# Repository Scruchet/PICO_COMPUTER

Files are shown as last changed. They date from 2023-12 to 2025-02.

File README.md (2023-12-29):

# PICO Computer Project: Motherboard

Welcome to my PICO Computer project repository. This section consolidates all the source files written in the C language used by my motherboard, as well as the electronic components created with KiCad. The primary goal of this project is to create a motherboard that can be connected to other boards (screen, keyboard, network) to build a Pico Computer.

## Part 1: Motherboard
You can find all the plans for my board in the **Motherboard_pico** directory.

### Features
This board is composed of multiple components. The main IC is the Atmega328p, which acts as the processor. The FTDI serves as the connection between the USB port and the Atmega328p (it does not include USB). The AT45DB641E is the storage component of the computer. As this component works with 3.3V signals, a buffer is needed to convert the 5V signals from the Atmega328p to 3.3V. To connect all the other cards, there are 5 HE10 connectors. All the different cards communicate using SPI (MOSI, MISO, SS, SCK).

## Part 2: Source Section (src)

This section includes all the source files written in the C language used by my motherboard. In addition to the source files, there is also a test folder to demonstrate various evaluations performed during the project's development.

### Module Details

#### Makefile
The Makefile enables project compilation and management. Refer to this file for details on compilation, linking, and other build tasks. In each directory, you can run the code (excluding files without main.c) and upload the code using the `make upload` command.

#### Memory
The Memory directory contains files related to memory management, including handling a specific flash memory (AT45DB641E).

#### Scheduler
The Scheduler module includes files necessary for implementing a scheduler. Refer to `makefile`, `scheduler.c`, and `scheduler.h` for more details.

#### SPI
The SPI module contains the files `spi.c` and `spi.h` for managing communication via the Serial Peripheral Interface (SPI) bus.

#### UART
The UART module includes the files `UART.c` and `UART.h`, dedicated to asynchronous serial communication (UART).

#### Tests
The Tests directory includes several subdirectories, each containing specific tests.

- `7seg`: Tests related to the 7-segment display (https://www.sparkfun.com/products/11441).
- `Mat_leds`: Tests for the LED matrix (https://www.sparkfun.com/products/retired/760).
- `Mem`: Tests for memory management.
- `UART_SPI`: Tests for UART and SPI modules.

# Contact
Thank you for visiting my project. If you have any comments or questions, please feel free to contact me via email at the following address: cruchetsimon@gmail.com

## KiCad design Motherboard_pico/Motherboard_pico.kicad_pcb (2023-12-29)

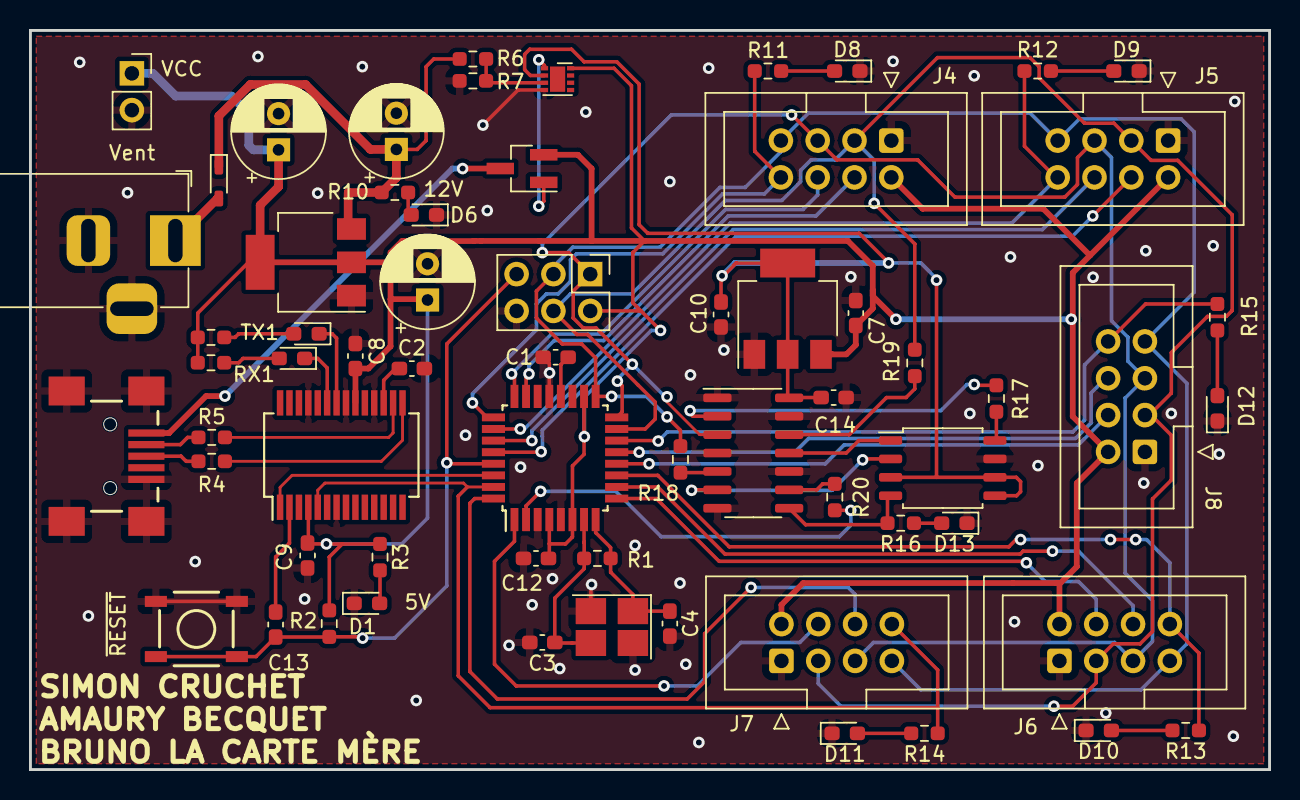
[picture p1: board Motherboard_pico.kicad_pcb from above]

Board: 2 copper layers, 85.5 x 51.0 mm, 64 parts (0 on the bottom side), 58 nets.

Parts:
C1, C8, C9, C12, C13, C14: 100nF; C_0603_1608Metric_Pad1.08x0.95mm_HandSolder
C2: C; C_0603_1608Metric_Pad1.08x0.95mm_HandSolder
C3, C4: 22pF; C_0603_1608Metric_Pad1.08x0.95mm_HandSolder
C5: 4.7µF; CP_Radial_D6.3mm_P2.50mm
C6, C11: 47µF; CP_Radial_D6.3mm_P2.50mm
C7, C10: 1µF; C_0603_1608Metric_Pad1.08x0.95mm_HandSolder
D1, D6, D8, D9, D10, D11, D12, D13: LED; LED_0603_1608Metric_Pad1.05x0.95mm_HandSolder
D7: D; D_SC-80_HandSoldering
IC1: AT45DB641E-SHN2B-T; SOIC-8_5.275x5.275mm_P1.27mm
J1: Barrel_Jack_Switch_Pin3Ring; BarrelJack_Horizontal
J2: AVR-ISP-6; PinHeader_2x03_P2.54mm_Vertical
J3: Conn_01x02_Socket; PinSocket_1x02_P2.54mm_Vertical
J4, J5, J6, J7, J8: Conn_02x04_Counter_Clockwise; IDC-Header_2x04_P2.54mm_Vertical
J9: USB_MINI-B_SMT; USB-MINIB
Q1: FDN340P; SOT-23_Handsoldering
R1: 1MΩ; R_0603_1608Metric_Pad0.98x0.95mm_HandSolder
R2: 10KΩ; R_0603_1608Metric_Pad0.98x0.95mm_HandSolder
R3, R8, R9: 500Ω; R_0603_1608Metric_Pad0.98x0.95mm_HandSolder
R4, R5: 22Ω; R_0603_1608Metric_Pad0.98x0.95mm_HandSolder
R6, R7: 10k; R_0603_1608Metric_Pad0.98x0.95mm_HandSolder
R10: 1kΩ; R_0603_1608Metric_Pad0.98x0.95mm_HandSolder
R11, R12, R13, R14, R15, R16: 1k; R_0603_1608Metric_Pad0.98x0.95mm_HandSolder
R17, R18, R19, R20: 3.3k; R_0603_1608Metric_Pad0.98x0.95mm_HandSolder
RX1: LED; LED_0603_1608Metric_Pad1.05x0.95mm_HandSolder
S1: MOMENTARY-SWITCH-SPST-2-SMD-5.2MM; TACTILE_SWITCH_SMD_5.2MM
TX1: LED; LED_0603_1608Metric_Pad1.05x0.95mm_HandSolder
U1: ATmega328P-A; TQFP-32_7x7mm_P0.8mm
U2: LM358; DFN-8-1EP_2x2mm_P0.5mm_EP1.05x1.75mm
U3: AMS1117-5.0; SOT-223-3_TabPin2
U4: AMS1117; SOT-223-3_TabPin2
U5: 74LVC125; SOIC-14_3.9x8.7mm_P1.27mm
U6: FT232RL; SSOP-28_5.3x10.2mm_P0.65mm
Y1: 16MHz; Crystal_SMD_SeikoEpson_FA238-4Pin_3.2x2.5mm_HandSoldering

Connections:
3.3V: C10.1, C14.1, IC1.3 (~RESET), IC1.5 (~WP), IC1.6 (VCC), U2.2 (-), U4.2 (VO), U5.14 (VCC)
12V: C11.1, D7.1 (K), R6.2, R10.1, U3.3 (VI)
CBUS0: RX1.1 (K), U6.23 (CBUS0)
CBUS1: TX1.1 (K), U6.22 (CBUS1)
CS1: R20.1, U1.2 (PD4)
CS1_1: IC1.4 (~CS), R16.2, U5.8
CS2: J4.8, R11.2, U1.25 (PC2)
CS3: J5.8, R12.2, U1.26 (PC3)
CS4: J6.8, R13.2, U1.11 (PD7)
CS5: J7.8, R14.2, U1.31 (PD1), U6.5 (RXD)
CS6: J8.8, R15.2, U1.14 (PB2)
D+: R4.2, U6.15 (USBD+)
D-: R5.2, U6.16 (USBD-)
GND: C1.2, C2.2, C3.2, C4.2, C5.2, C6.2, C7.2, C8.2, C9.2, C10.2, C11.2, C12.2, C14.2, D1.1 (K), D6.1 (K), D8.1 (K), D9.1 (K), D10.1 (K), D11.1 (K), D12.1 (K), D13.1 (K), IC1.7 (GND), J1.2, J1.3, J2.6 (GND), J3.2, J4.1, J5.1, J6.1, J7.1, J8.1, J9.GND, J9.S1 (SHIELD), J9.S2 (SHIELD), J9.S3 (SHIELD), J9.S4 (SHIELD), R7.2, S1.1, S1.2, U1.3 (GND), U1.5 (GND), U1.21 (GND), U2.4 (V-), U3.1 (GND), U4.1 (ADJ), U5.1, U5.4, U5.7 (GND), U5.10, U5.13, U6.7 (GND), U6.18 (GND), U6.21 (GND), U6.25 (AGND), Y1.2, Y1.4
INT1: J4.4, U1.23 (PC0)
INT2: J5.4, U1.28 (PC5)
INT3: J6.4, U1.9 (PD5)
INT4: J7.4, U1.1 (PD3)
INT5: J8.4, U1.12 (PB0)
MISO: J2.1 (MISO), J4.5, J5.5, J6.5, J7.5, J8.5, U1.16 (PB4), U5.3
MISO_1: IC1.8 (SO), R17.1
MOSI: J2.4 (MOSI), J4.3, J5.3, J6.3, J7.3, J8.3, R19.1, U1.15 (PB3)
MOSI_1: IC1.1 (SI), U5.11
unnamed: D1.2 (A), R3.2
unnamed: D6.2 (A), R10.2
unnamed: D7.2 (A), J1.1
unnamed: D8.2 (A), R11.1
unnamed: D9.2 (A), R12.1
unnamed: D10.2 (A), R13.1
unnamed: D11.2 (A), R14.1
unnamed: D12.2 (A), R15.1
unnamed: D13.2 (A), R16.1
unnamed: J9.D+, R4.1
unnamed: J9.D-, R5.1
unnamed: Q1.1 (G), U2.1
unnamed: R17.2, U5.2
unnamed: R18.2, U5.5
unnamed: R19.2, U5.12
unnamed: R20.2, U5.9
unnamed: R8.2, RX1.2 (A)
unnamed: R9.2, TX1.2 (A)
unnamed: C1.1, U1.20 (AREF)
unnamed: C3.1, R1.2, U1.7 (XTAL1/PB6), Y1.3
unnamed: C4.1, R1.1, U1.8 (XTAL2/PB7), Y1.1
unnamed: R6.1, R7.1, U2.3 (+)
unnamed: C2.1, U6.17 (3V3OUT)
unnamed: C13.2, U6.2 (DTR)
RESET: C13.1, J2.5 (~RST), R2.2, S1.3, S1.4, U1.29 (~RESET/PC6)
RST1: J4.6, U1.24 (PC1)
RST2: J5.6, U1.27 (PC4)
RST3: J6.6, U1.10 (PD6)
RST4: J7.6, U1.32 (PD2)
RST5: J8.6, U1.13 (PB1)
SCK: J2.3 (SCK), J4.7, J5.7, J6.7, J7.7, J8.7, R18.1, U1.17 (PB5)
SCK_1: IC1.2 (SCK), U5.6
TX: U1.30 (PD0), U6.1 (TXD)
VCC: C5.1, C6.1, C7.1, C8.1, C9.1, C12.1, J2.2 (VCC), J3.1, J4.2, J5.2, J6.2, J7.2, J8.2, Q1.2 (S), R2.1, R3.1, R8.1, R9.1, U1.4 (VCC), U1.6 (VCC), U1.18 (AVCC), U2.8 (V+), U3.2 (VO), U4.3 (VI), U6.4 (VCCIO), U6.20 (VCC)
VUSB: J9.VBUS, Q1.3 (D)

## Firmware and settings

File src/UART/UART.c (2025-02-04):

#include "UART.h"

unsigned char serialCheckTxReady(void)
{
    return (UCSR0A & _BV(UDRE0)); // nonzero if transmit register is ready to receive new data.
}

void serialsend(unsigned char DataOut)
{
    while (serialCheckTxReady() == 0) // while NOT ready to transmit
    {
        ;
        ;
    }
    UDR0 = DataOut;
}

void serialWrite(char* Data)
{
    for (int i = 0; i < strlen(Data); i++) {
        serialsend((unsigned char)Data[i]);
    }
}

unsigned char serialCheckRxComplete(void)
{
    return (UCSR0A & _BV(RXC0)); // nonzero if serial data is available to read.
}

unsigned char serialRead(void)
{
    while (!(UCSR0A & (1 << RXC0))) // While data is NOT available to read
    {
        ;
        ;
    }
    return UDR0;
}

void serialInit(void)
{
    // Serial Initialization
    /*Set baud rate 9600 */
    UBRR0H = (unsigned char)((MYUBRR) >> 8);
    UBRR0L = (unsigned char)MYUBRR;
    /* Enable receiver and transmitter */
    UCSR0B = (1 << RXEN0) | (1 << TXEN0);
    /* Frame format: 8data, No parity, 1stop bit */
    UCSR0C = (3 << UCSZ00);
}


// Permet d'afficher des chaines de caractères sur le bus UART
//  int main(){
//      serialInit();
//      spi_init();
//      char *phrase = "Bonjour le monde\r\n";
//      while(1){
//              serialWrite(phrase);
//              _delay_ms(1000);
//      }
//      return 0;
//  }
// Permet d'afficher 2222 si sur a sur le port serie 9999 si autre caractère
//  int main(){
//      serialInit();
//      spi_init();
//
//      unsigned char receivedChar;
//
//      while(1){
//          receivedChar = serialRead();
//          if (receivedChar == 'a'){
//                  afficher_nombre(2222, CS[2]);
//          }
//          else
//              afficher_nombre(9999, CS[2]);
//      }
//
//  }

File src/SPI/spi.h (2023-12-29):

#include <avr/interrupt.h>
#include <avr/io.h>
#include <avr/pgmspace.h>
#include <avr/sleep.h>
#include <stdio.h>
#include <util/delay.h>

#ifndef SPI_H
#define SPI_H

// Différents ports et leurs attributions
#define MOSI PB3
#define SCK PB5
#define MISO PB4
#define CS1 PD4
#define CS2 PC2
#define CS3 PC3
#define CS4 PD7
#define CS5 PD1
#define CS6 PB2

// Différentes commandes pour la transmission SPI
#define C_NET 0X76
#define C_LUM 0x7A
#define C_MIL 0x7B
#define C_CEN 0x7C
#define C_DIX 0x7D
#define C_UNI 0x7E
#define LUM_MAX 255

// Différentes couleur pour la matrice

#define MAT_BLACK 0x00
#define MAT_ROUGE 0xE0
#define MAT_VERT 0x1C
#define MAT_BLEU 0x03
#define MAT_VIOLET 0xE3
#define MAT_LOBSTER 0x1F
#define BLANC 0xFF

// Structure pour les différents esclaves
typedef struct cs {
    uint8_t pin;
    volatile uint8_t* port;
} cs_t;





// Prototype des fonctions
void spi_init();
void set_desactiver(cs_t tab_cs);
void set_activer(cs_t tab_cs);
uint8_t SPI_trans(uint8_t data);
void nettoyerEcran(cs_t tab_cs);
void luminosite_ecran(uint8_t value, cs_t cs);
void afficher_nombre(unsigned short int valeur, cs_t cs);
void mettre_couleur(uint8_t couleur, cs_t cs);
//
#endif // SPI_H

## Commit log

2023-12-29 project files
    [Motherboard_pico-B_Cu.gbr, Motherboard_pico-B_Mask.gbr, Motherboard_pico-B_Paste.gbr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]
2023-12-29 Modification on README
    [_saved_boostboard1.sch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]
2025-02-04 UART TEST
